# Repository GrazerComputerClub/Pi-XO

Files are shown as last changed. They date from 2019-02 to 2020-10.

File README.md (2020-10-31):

# Pi-XO
Raspberry Pi Zero game console for use with PICO-8.   
Development discontinued  

If you are interested in a PCB board or components, please contact us via our email.

## In Action

Pi-XO Gaming (https://www.youtube.com/watch?v=vgGREFB0JgY)

## Errata

Rev. 01. board  error:
  - **Error:** Speaker- an audio amp. output- connected to GND.  
    **Solution:** Do not wire speaker and audio amp. output (PAD5 and PAD6) to PCB, please connect speaker to audio amp. output via wire.  
    **Drawback:** Headphone connector not working 
  - **Error:**  ADC input direct connected to batterie A result in applying ~0.6 V to 3.3 V supply if battery is attached and device is off.  
    **Solution:** Do not assemble MCP3202 (IC1).  
    **Drawback:** No battery monitoring possible.
  - **Error:**  Dual NiMH AA-Batteries in combination with DD0606SA_3V7 - DC/DC Step Up Converter cannot provide enough current for Wi-Fi operation (consumes up to 250 mA).  
    **Solution 1:** Use Raspberry Pi Zero v1.3 or switch off Wi-Fi at Raspberry Pi Zero W/WH.  
    **Drawback:** Download of games only via Eternet OTG Mode possible or manual copy to sd card  
    **Solution 2:** Use 4xAAA NiMH battery without DC/DC Step Up Converter 
    
## Features

- **Multiple display options** - 160x128 or 320x240   
- **Audio (speaker / headphone)**
- **Classic NiMH battery supply**
- **Battery monitoring**
- **GPIOs (LED bar)**
- **Vibration motors**
- **Low cost**

## OS installation

- Download latest Raspjamming-Image https://github.com/GrazerComputerClub/Raspjamming-Image and flash to SD card
- Unzip PICO-8-rasp.zip (https://www.lexaloffle.com/pico-8.php) to boot partition (Executable needed pico-8/pico8) from 
- Activate line 'include Pi-XO.txt' in config.txt file
- Activate correct Display Option 1-3 including resolution in Pi-XO.txt file 
   * Display 1: 320x240 Display mounted far right side (9 pin, BK-LED regulation)
   * Display 2: 160x128 Display mounted right side (8 pin, BK-LED regulation) 
   * Display 3: 160x128 Display mounted left side  (11 pin, BK-LED fixed on) 

## Functions button

- Fn-Button and Up/Down-Button: Volume control
- Fn-Button and Left/Right-Button: Display brightness (Display 1 and 2)
- Fn-Button and P-Button: Shutdown

## Diagrams and pictures

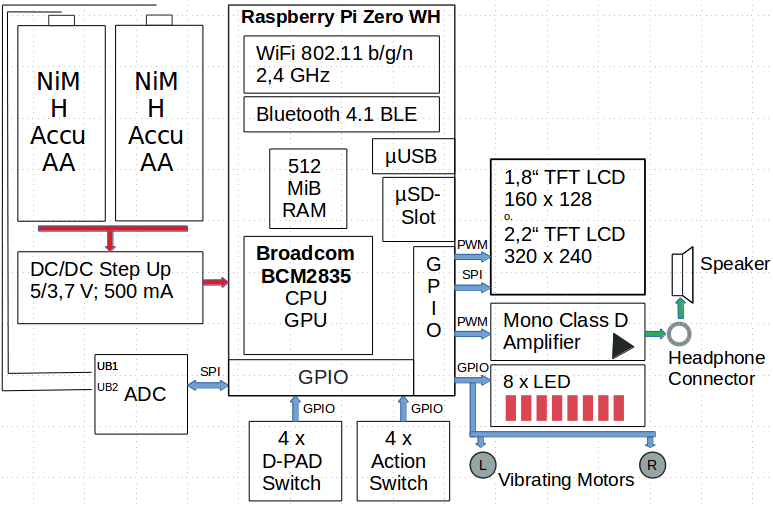
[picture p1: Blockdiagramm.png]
block diagram
 

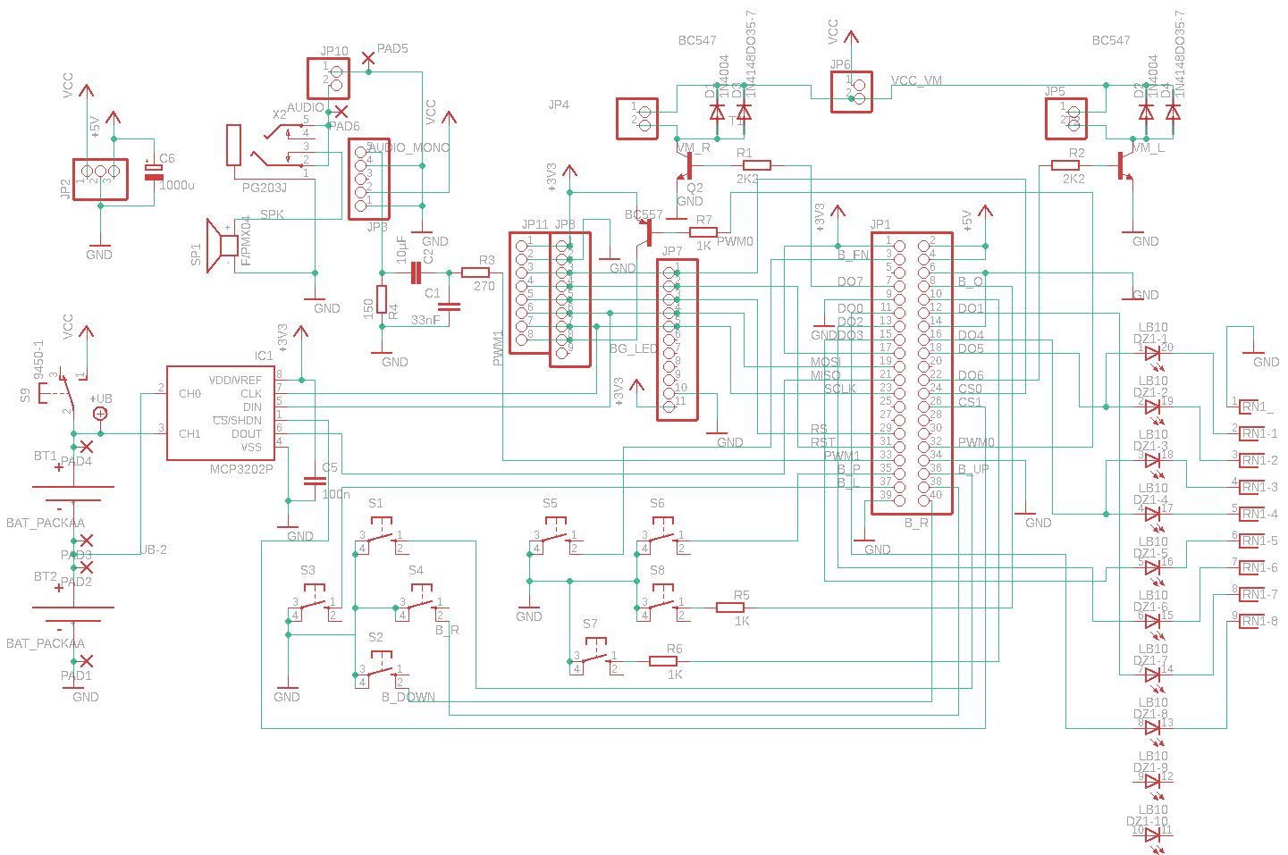
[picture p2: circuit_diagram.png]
Circuit diagram


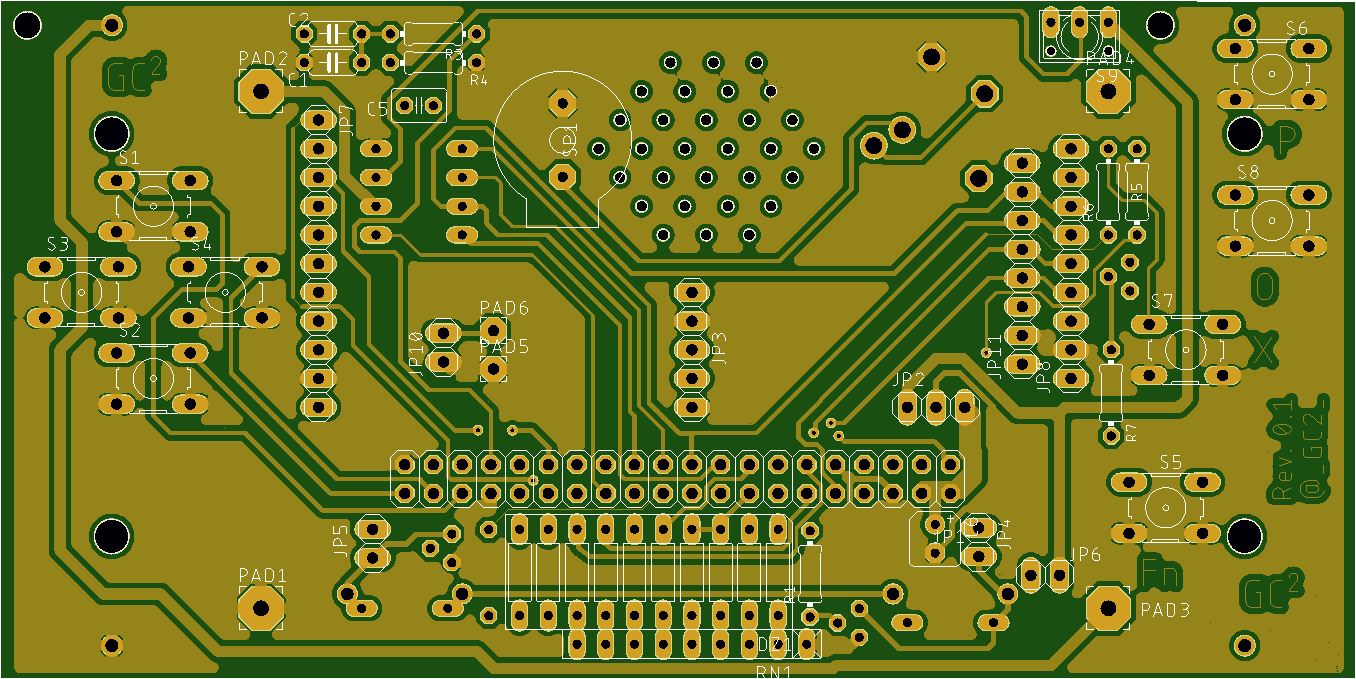
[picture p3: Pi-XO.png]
PCB Top


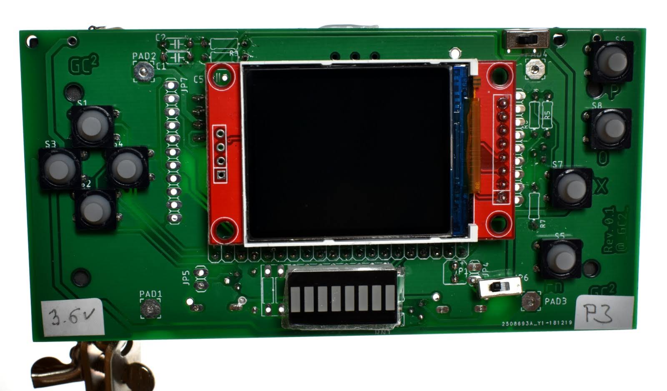
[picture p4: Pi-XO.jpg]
Pi-XO


## Assembling

### Components list
	
 1 x Female pin header socket 2x20  (JP1)
 1 x Switch 3-pin (S9, Device on/off)  
 1 x 2Pin + Jumper or Switch 2-pin (JP6, vibration motors on/off)    
 8 x Tactile switch 6x6mm (S1-S8)  
     https://www.reichelt.com/at/en/short-stroke-key-6x6-mm-height-5-0-mm-12-v-vertical-taster-9302-p44579.html  
 1 x Audio amplifier board PAM8302 (JP3, do not connect PAD5 and PAD6)  
     https://www.ebay.de/sch/i.html?_nkw=PAM8302  
 1 x DD0606SA_3V7 - DC/DC Step Up Converter to 3.7V (JP2)  
     https://www.google.com/search?q=DD0606SA_3V7  
 1 x Speaker 8 Ohm (connect to amplifier board PAM8302 Output via wire, SP1)  
     https://www.reichelt.com/at/en/metal-speaker-soldered-connection-lsm-36m-b-p145887.html  
     https://www.neuhold-elektronik.at/catshop/product_info.php?products_id=6645  
 1 x LED bar 8 segments (LB10, align right site)  
     https://www.ebay.at/sch/i.html?_from=R40&_trksid=m570.l1313&_nkw=8-Segment+Red+Color+Bar  
 1 x Resistor array 1K (RN1)  
     https://secure.reichelt.at/resistor-network-8-res-9-pin-1-0-k-x2126-sil-9-8-1-0k-p18012.html  
 2 x Vibration motor (JP4, JP5)  
     https://www.neuhold-elektronik.at/catshop/product_info.php?products_id=6971  
 2 x AA Batterie holder (needs DC/DC Step Up Converter) or dual AAA Batteries holder (no DC/DC Step Up Converter needed) (PAD1, PAD2, PAD3, PAD4)  
     https://secure.reichelt.at/battery-holder-1x-mignon-aa-halter-1xaap-p113168.html  
     https://secure.reichelt.at/holder-for-1-mignon-cell-aa-solder-tag-halter-1xum3-lf-p8434.html  
     https://secure.reichelt.at/battery-holder-2x-mignon-aa-halter-2xaaz-p113169.html  
 2 x BC547B transiior (T1, T2)  
     https://secure.reichelt.at/npn-to-92-transistor-45-v-0-1-a-0-5-w-bc-547b-p5006.html  
 1 x BC557B transistor (Q2)  
     https://secure.reichelt.at/transistor-pnp-to-92-45-v-0-1-a-0-5-w-bc-557b-p35845.html  
 2 x Resistor 2K2 Ohm (Transistor base vibration motor: R1, R2)  
 1 x Resistor 270 Ohm (Audio filter: R3)  
 1 x Resistor 150 Ohm (Audio filter: R4)  
 3 x Resistor 1K Ohm (protection UART: R5, R6; transistor background LED display: R7)   
 1 x Capacitor 33 nF (C1)  
 1 x Electrolytic capacitor 10 uF/6.3 V (C2)  
 1 x Capacitor 100 nF (C5)  
 1 x Electrolytic capacitor 330 uF/6.3 V (C6)  
 1 x MCP3202 (IC1, do not connect)  
     https://www.conrad.at/de/p/microchip-technology-mcp3202-ci-p-datenerfassungs-ic-analog-digital-wandler-adc-extern-pdip-8-651461.html  
 1 x Headphone connector (X2, do not connect)  
     https://secure.reichelt.at/jack-socket-3-5-mm-pcb-with-switch-contact-ebs-35-p7301.htm  
 2 x Diode 1N4001 (D2 or D4, D1 or D3)  
     https://secure.reichelt.at/rectifier-diode-do41-50-v-1-a-1n-4001-p1723.html  
 1 x 1,8" Display 160x128 ST7735 11-pin (JP7) or 8-pin (JP11) - https://www.ebay.de/sch/i.html?_nkw=1.8+128x160+ST7735  
     2,2" Display 320x240 ILI9341 9-pin (JB8) - https://www.ebay.de/sch/i.html?_nkw=2.2+ILI9341+240x320

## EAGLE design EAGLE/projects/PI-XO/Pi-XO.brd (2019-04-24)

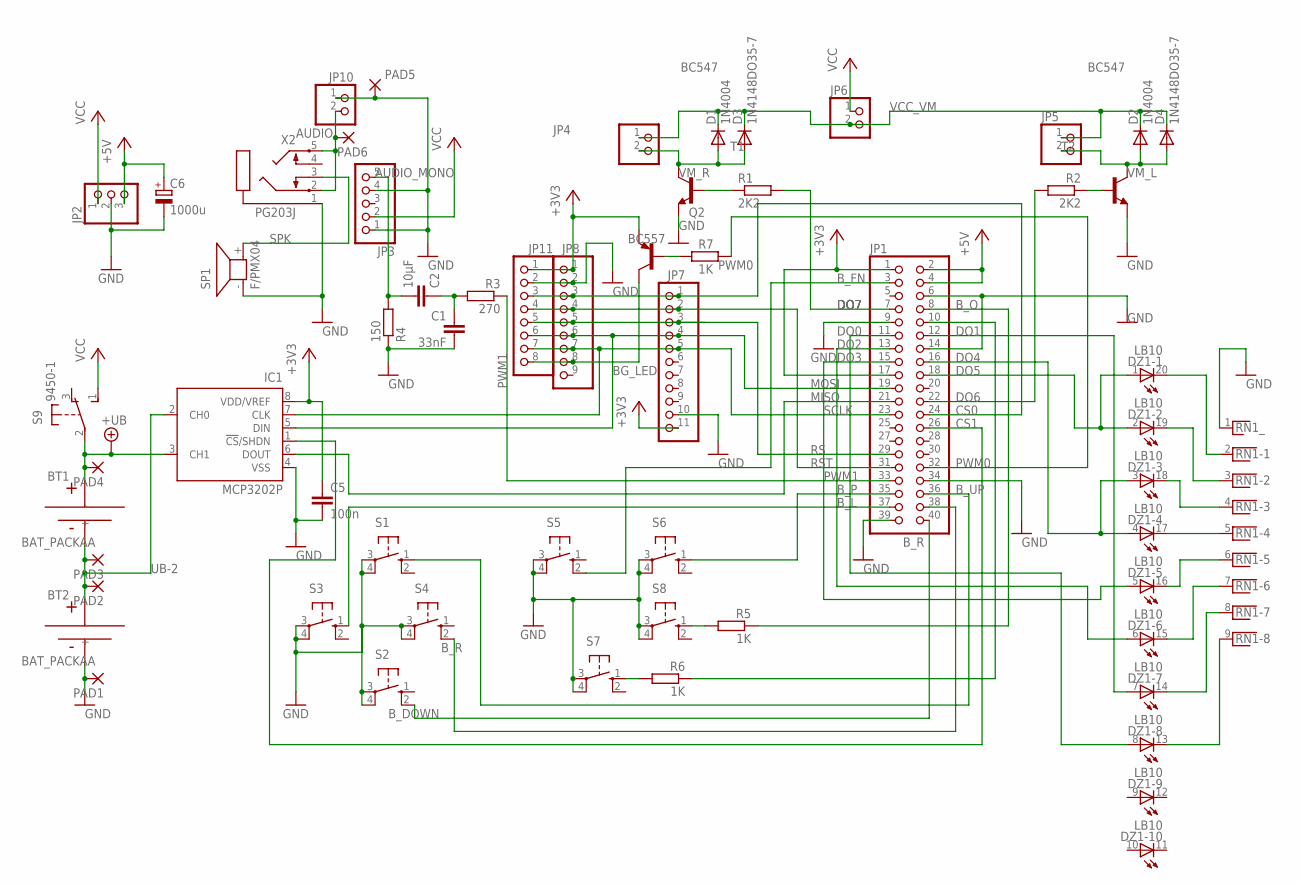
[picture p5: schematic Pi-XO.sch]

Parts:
BT1, BT2: BAT_PACKAA; BHAA-3
C1: 33nF; C050-024X044
C2: 10µF; C050-024X044
C5: 100n; C025-030X050
C6: 1000u; B45181A
D1, D2: 1N4004; DO41-10
D3, D4: 1N4148DO35-7; DO35-7
DZ1: LB10
IC1: MCP3202P; DIL8
JP1: PINHD-2X20; 2X20
JP2: PINHD-1X3; 1X03
JP3: PINHD-1X5; 1X05
JP4, JP5, JP6, JP10: PINHD-1X2; 1X02
JP7: PINHD-1X11; 1X11
JP8: PINHD-1X9; 1X09
JP11: PINHD-1X8; 1X08
PAD1, PAD2, PAD3, PAD4: 3,81/1,4
PAD5, PAD6: 2,15/1,0
Q2: BC557; TO92
R1, R2: 2K2; 0204/7
R3: 270; 0204/7
R4: 150; 0204/7
R5, R6, R7: 1K; 0204/7
RN1: RNX8; RN-9
S1, S2, S3, S4, S5, S6, S7, S8: 10-XX; B3F-10XX
S9: 9450-1
SP1: F/PMX04; F/PMX04A
T1, T2: BC547; TO92
X2: PG203J

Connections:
+3V3: C5.1, IC1.8 (VDD/VREF), JP1.1, JP1.17, JP7.11, JP8.1, JP11.1, Q2.1 (E)
+5V: C6.+, JP1.2, JP1.4, JP2.3
+UB: BT1.+, IC1.3 (CH1), PAD4.1, S9.2
AUDIO: JP10.2, PAD6.1, X2.2, X2.5
AUDIO_MONO: C2.2, JP3.5, R4.2
BG_LED: JP8.8, JP11.8, Q2.3 (C)
B_DOWN: JP1.40, S2.2 (S1)
B_FN: JP1.3, S5.2 (S1)
B_L: JP1.37, S3.1 (S)
B_O: JP1.8, R5.1
B_P: JP1.35, S6.1 (S)
B_R: JP1.38, S4.2 (S1)
B_UP: JP1.36, S1.1 (S)
B_X: JP1.10, R6.1
CS0: JP1.24, JP7.1, JP8.3, JP11.3
CS1: IC1.1 (!CS!/SHDN), JP1.26
DO0: DZ1.8 (A), JP1.11
DO1: DZ1.7 (A), JP1.12
DO2: DZ1.6 (A), JP1.13
DO3: DZ1.5 (A), JP1.15
DO4: DZ1.3 (A), DZ1.4 (A), JP1.16
DO5: DZ1.1 (A), DZ1.2 (A), JP1.18
DO6: JP1.22, R2.2
DO7: JP1.7, R1.2
GND: BT2.-, C1.2, C5.2, C6.-, IC1.4 (VSS), JP1.6, JP1.9, JP1.14, JP1.34, JP1.39, JP2.2, JP3.1, JP3.4, JP7.10, JP8.2, JP10.1, JP11.2, PAD1.1, PAD5.1, R4.1, RN1.1, S1.3, S1.4 (P1), S2.3, S2.4 (P1), S3.3, S3.4 (P1), S4.3, S4.4 (P1), S5.3, S5.4 (P1), S6.3, S6.4 (P1), S7.3, S7.4 (P1), S8.3, S8.4 (P1), SP1.- (1), T1.1 (E), T2.1 (E), X2.1
MISO: IC1.6 (DOUT), JP1.21
MOSI: IC1.5 (DIN), JP1.19, JP7.4, JP8.6, JP11.6
unnamed: C1.1, C2.1, R3.2
unnamed: R1.1, T1.2 (B)
unnamed: R2.1, T2.2 (B)
unnamed: DZ1.20 (C), RN1.2
unnamed: DZ1.19 (C), RN1.3
unnamed: DZ1.18 (C), RN1.4
unnamed: DZ1.17 (C), RN1.5
unnamed: DZ1.16 (C), RN1.6
unnamed: DZ1.15 (C), RN1.7
unnamed: DZ1.14 (C), RN1.8
unnamed: DZ1.13 (C), RN1.9
unnamed: R5.2, S8.1 (S)
unnamed: R6.2, S7.1 (S)
unnamed: Q2.2 (B), R7.1
PWM0: JP1.32, R7.2
PWM1: JP1.33, R3.1
RS: JP1.29, JP7.3, JP8.5, JP11.5
RST: JP1.31, JP7.2, JP8.4, JP11.4
SCLK: IC1.7 (CLK), JP1.23, JP7.5, JP8.7, JP11.7
SPK: SP1.+ (2), X2.3
UB-2: BT1.-, BT2.+, IC1.2 (CH0), PAD2.1, PAD3.1
VCC: JP2.1, JP3.2, JP6.1, S9.1 (S)
VCC_VM: D1.C, D2.C, D3.C, D4.C, JP4.1, JP5.1, JP6.2
VM_L: D2.A, D4.A, JP5.2, T2.3 (C)
VM_R: D1.A, D3.A, JP4.2, T1.3 (C)

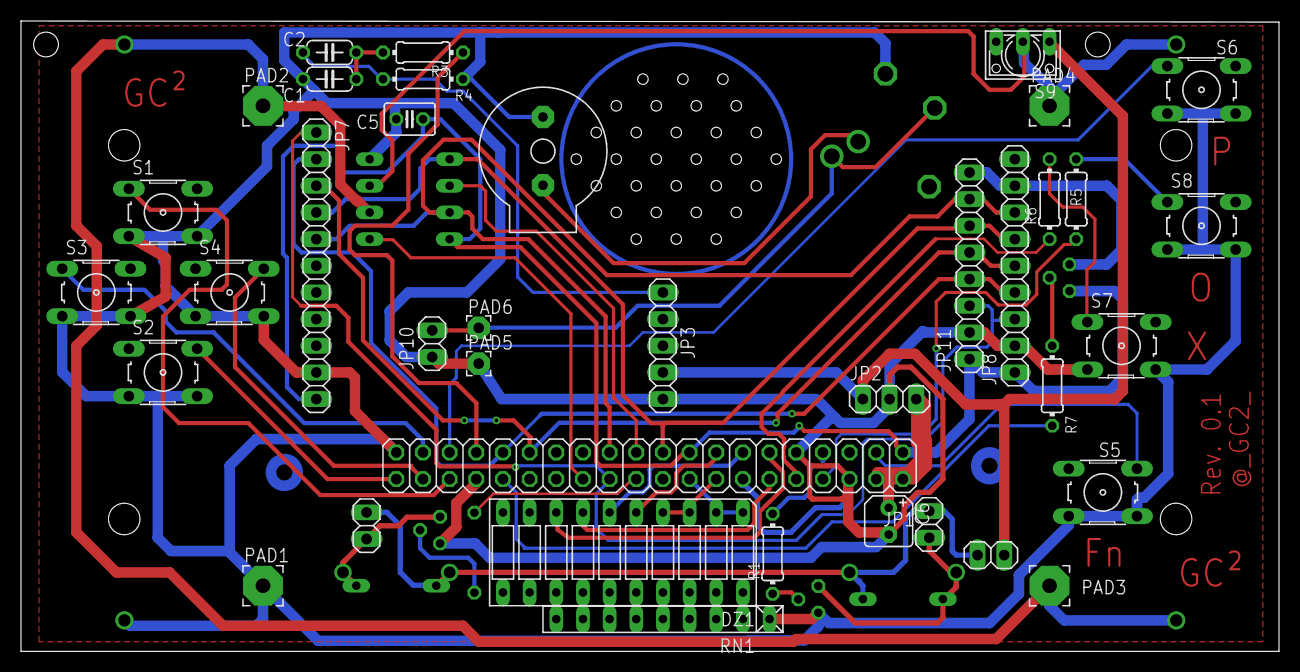
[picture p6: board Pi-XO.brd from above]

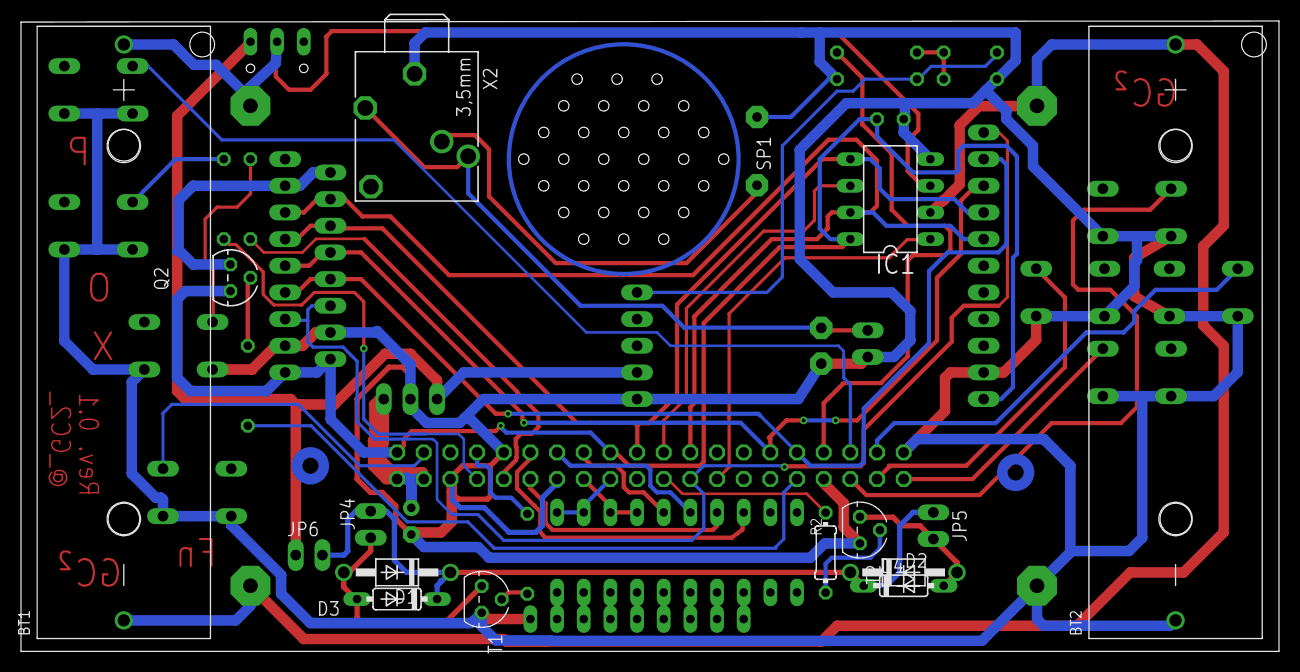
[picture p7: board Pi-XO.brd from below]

Board: 2 copper layers, 119.8 x 60.0 mm, 50 parts (12 on the bottom side), 52 nets.

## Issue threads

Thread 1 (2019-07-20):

Next hardware release

mstroh76, 2019-07-20:
-     Solve errata
-     Secure operation with USB connector supply together with batteries
-     Audio and vibration motors works with direct USB connector supply
-     8x instead of 10x LED-bar
-     connect vibration motors to GPIO port with default pull-down resistor
-     optimize for 4xAAA or 3xAA and remove DC-DC converter
-     FET instead of transistor for backlight control
-     HAT EEPROM
-     3 stage resistor divider 100K (10k+1K) for each ADC input, 1:10 divider
-     ADC input work with USB connector supply too
-     Remove the optional big diode
